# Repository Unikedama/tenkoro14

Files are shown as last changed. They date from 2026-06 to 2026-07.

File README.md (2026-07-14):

# Tenkoro14

**トラックボール搭載 右手用テンキーデバイス**

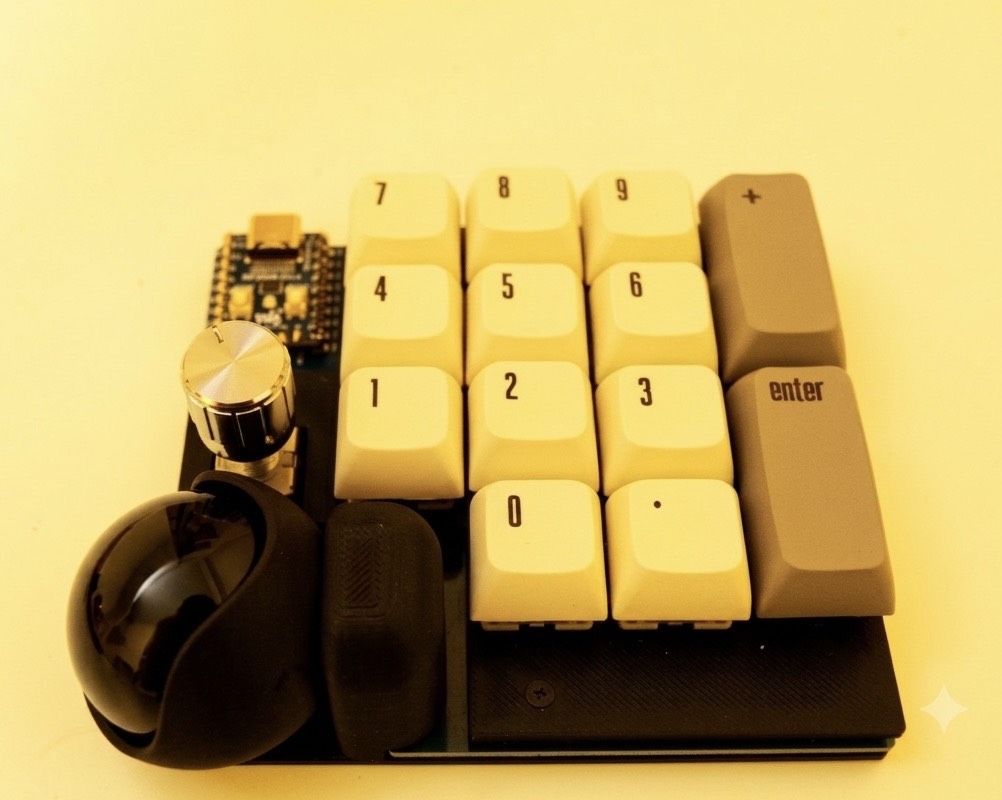
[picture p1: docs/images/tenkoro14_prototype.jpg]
Tenkoro14


---

## 概要

Tenkoro14は、トラックボールマウスとテンキーの機能を1台に凝縮した右手用デバイスです。

マウスとテンキーの間で手を移動させることなく、トラックボールでセルを選択してそのまま数値入力できます。Excelなどの表計算ソフトでの作業効率が大幅に向上します。

### 特徴

- **14キー**：Numpad 0〜9、`.`、`Enter`、`+`、カスタマイズ可能な1キー
- **トラックボール**：Keyball方式（PMW3610センサー）
- **オートマウスレイヤー**：トラックボール操作時に自動でマウスレイヤーに切り替え
- **ロータリーエンコーダ対応**：1キーをロータリーエンコーダに換装可能
- **Keyballトラックボールケース互換**：Keyball用ケースがそのまま使用可能
- **ダイオードレス設計**：はんだづけ箇所を最小限に
- **ホットスワップ＆直付け対応**：初心者から上級者まで対応

---

## 使用例

- **Excel / スプレッドシート**：トラックボールでセルを選択 → そのまま数値入力
- **DAW / 動画編集**：ロータリーエンコーダで音量・タイムライン操作
- **特定アプリ専用デバイス**：Vialでレイヤーをカスタマイズ

---

## スペック

| 項目 | 内容 |
|---|---|
| キー数 | 14キー |
| マイコン | RP2040 Zero |
| トラックボールセンサー | PMW3610 |
| トラックボールケース | Keyball互換 |
| キースイッチ | MX互換（ホットスワップ / 直付け両対応） |
| ファームウェア | QMK / Vial |
| 接続 | USB-C |

---

## 必要部品（BOM）

### 共通部品（すべての構成で必要）

| 部品 | 数量 | 備考 |
|---|---|---|
| PCB | 1 | |
| L字コンスルー 7pin（マックエイト） | 1 | PMW3610接続用・キット同梱 |
| PMW3610 ブレイクアウトボード | 1 | roBa互換品・キット同梱 |
| トラックボールケース | 1 | Keyball用互換品・キット同梱 |
| ピンヘッダ（9pin×2、5pin×1） | 1セット | RP2040 Zero取り付け用・キット同梱 |
| RP2040 Zero | 1 | |
| キースイッチ（MX互換） | 14 | |
| キーキャップ（1U） | 11〜12 | テンキー用を推奨（※下記注意事項参照） |
| キーキャップ（2U） | 2 | |
| ホットスワップソケット | 14 | 直付けの場合は不要 |
| M1.7ネジ | 2 | トラックボールケース固定用・キット同梱 |
| トラックボール（ボール） | 1 | 推奨：25mm／34mmも使用可能（※下記注意事項参照） |
| ロータリーエンコーダ EC11 | 0〜1 | オプション |
| M2スペーサー（7mm） | 4 | ミドルアクリル（3mm）込みの高さ |
| M2ネジ（4〜5mm） | 8 | |
| USBケーブル（Type-C） | 1 | |

### プレート（いずれかを選択）

| 構成 | トッププレート | ミドルアクリル | ボトムプレート | 入手方法 |
|---|---|---|---|---|
| **キット** | FR4（同梱） | 透明アクリル（同梱） | 透明アクリル（同梱） | キット購入 |
| **PCBのみ／自作** | STLデータで3Dプリント可 | STLデータで3Dプリント可 | STLデータで3Dプリント可 | 本リポジトリのデータを使用 |
| **PCBのみ／発注** | FR4データで発注（JLCPCB等） | アクリルデータで発注（Elecrow等） | アクリルデータで発注（Elecrow等） | 本リポジトリのデータを使用 |

> ミドルアクリルはロータリーエンコーダ搭載位置に切り欠きあり。

### キーキャップについて

テンキー用キーキャップセットの使用を推奨します。

> ⚠️ 一般的なテンキー用キーキャップセットでは、`0`キーが**2U**（横2倍サイズ）で付属している場合があります。Tenkoro14では`0`キーに**1U**のキーキャップが必要です。購入の際はセット内容をご確認ください。

### トラックボール（ボール）のサイズについて

用途に合わせてボールサイズを選んでください。

- **34mm**：操作性が高く、トラックボールマウスとしての使い勝手を重視する方に。`0`キーが若干打ちにくく感じる場合があります。
- **25mm**：テンキー入力をメインに使う方に。全キーを快適に操作できます。

---

## ファームウェア

### ダウンロード

ファームウェア `tenkoro14_vial.uf2` は [`firmware/`](firmware/) または
[**Releases**](../../releases/latest) から入手できます。

> 🛠 自作用の設計データ（プレート切削用DXF・各STL・3Dプリントケース）は
> [`hardware/`](hardware/) にまとめてあります。

### 書き込み方法

1. BOOTボタンを押しながらUSB接続（または BOOTボタンを押しながらリセット）
2. `RPI-RP2` ドライブとして認識される
3. `tenkoro14_vial.uf2` をドライブにコピー
4. 自動的に再起動してキーボードとして認識される

### Vialでキーマップを変更

[Vial](https://get.vial.today/) を使用してキーマップをカスタマイズできます。

---

## ビルドガイド

→ [buildguide.md](docs/buildguide.md) を参照してください。

---

## 部品の購入先

以下のショップで必要な部品を購入できます。

| 部品 | 購入先 |
|---|---|
| RP2040 Zero | [Talpkeyboard](https://talpkeyboard.net/) / [遊舎工房](https://shop.yushakobo.jp/) |
| キースイッチ（MX互換） | [Talpkeyboard](https://talpkeyboard.net/) / [遊舎工房](https://shop.yushakobo.jp/) |
| ホットスワップソケット | [Talpkeyboard](https://talpkeyboard.net/) / [遊舎工房](https://shop.yushakobo.jp/) |
| トラックボール（ボール） | [遊舎工房](https://shop.yushakobo.jp/) / Amazon |
| キーキャップ | [Talpkeyboard](https://talpkeyboard.net/) / [遊舎工房](https://shop.yushakobo.jp/) |

---

## キーアサインのおすすめ

テンキー入力時に数字の打ち間違いが多い場面では、`+`キーに **`BS`または`Del`** を割り当てることをおすすめします。Vialで自由にカスタマイズできます。

## レイヤー構成（デフォルト）

| レイヤー | 内容 |
|---|---|
| Layer 0 | テンキー（Numpad） |
| Layer 1 | オートマウス（トラックボール操作時に自動切替） |
| Layer 2 | カスタム |

---

## ライセンス

- ファームウェア：[GPL-2.0](LICENSE)
- ハードウェア設計：© Unikedama

---

## クレジット・スペシャルサンクス
- トラックボール付きキーボード keyballの製作者：ヨーキース様をはじめとする、自作キーボード界隈の先輩方
- トラックボールケース：[kepeo](https://www.thingiverse.com/kepeo) 氏の設計（[CC BY 4.0](https://creativecommons.org/licenses/by/4.0/)）を一部改変して使用
- ファームウェア：[QMK Firmware](https://qmk.fm/) / [Vial](https://get.vial.today/)

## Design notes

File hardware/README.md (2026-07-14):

# hardware

tenkoro14 の自作用データ一式。

## plates_dxf/ — プレート切削発注用DXF（M2スペーサ穴あり）
| ファイル | 用途 | 材質 |
|---|---|---|
| tenkoro14_v1_TopPlate_FR4_99.9x89.96.dxf | トッププレート | FR4 1.6mm |
| tenkoro14_v1_MiddlePlate_acryl3mm_99.9x89.96.dxf | ミドルプレート | アクリル 3mm |
| tenkoro14_v1_BottomPlate_acryl2mm_99.97x89.88.dxf | ボトムプレート | アクリル 2mm |
| tenkoro14_v1_BottomPlate_Caseyou.dxf | ボトム（Caseyou発注用の別版） | アクリル 2mm |

## plates_stl/ — 各プレートのSTL（形状確認用）

## trackball_case/ — トラックボール部の3Dプリントケース（top/bottom）
kepeo氏データ（CC BY 4.0）の改変。

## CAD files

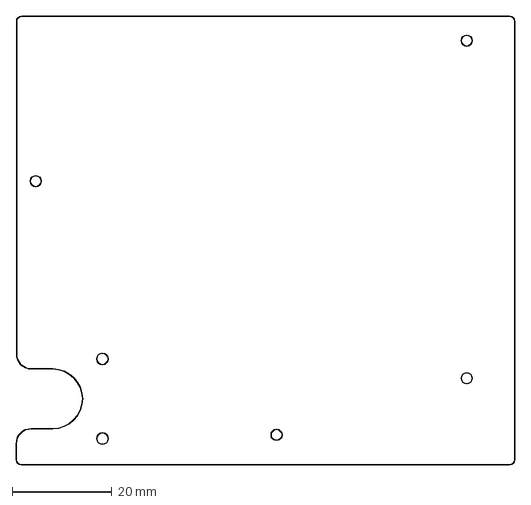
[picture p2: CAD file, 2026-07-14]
hardware/plates_dxf/tenkoro14_v1_BottomPlate_acryl2mm_99.97x89.88.dxf
100.0 x 89.9 mm

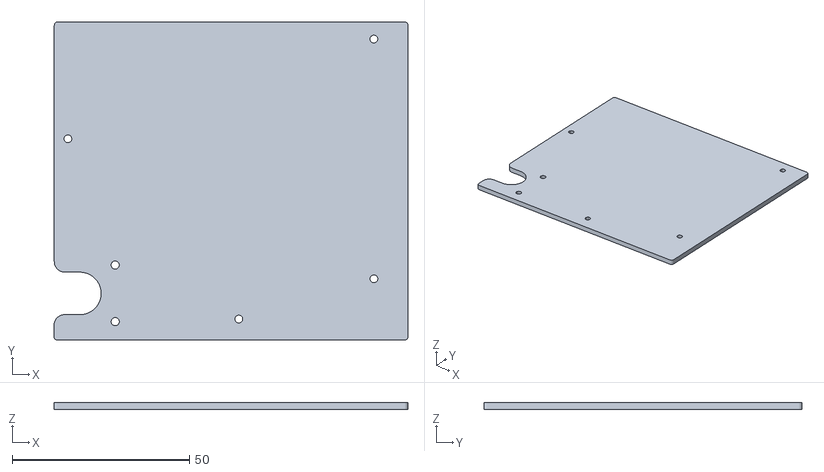
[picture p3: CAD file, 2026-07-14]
hardware/plates_stl/tenkoro_V1_bottom.stl
100.0 x 89.9 x 2.00

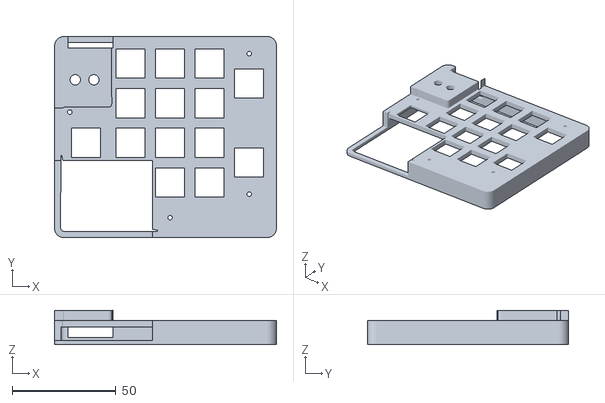
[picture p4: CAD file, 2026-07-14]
hardware/trackball_case/tenkoro14_trackball_case_top.stl
107.0 x 96.9 x 16.6

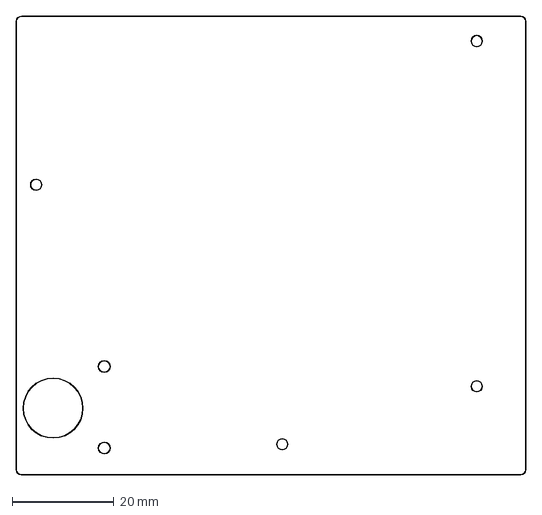
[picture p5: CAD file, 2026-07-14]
hardware/plates_dxf/tenkoro14_v1_BottomPlate_Caseyou.dxf
100.0 x 89.9 mm

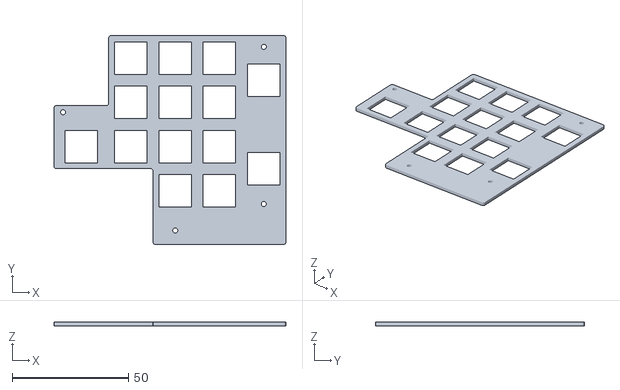
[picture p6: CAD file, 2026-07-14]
hardware/plates_stl/tenkoro14_v1_top.stl
99.9 x 90.0 x 1.60

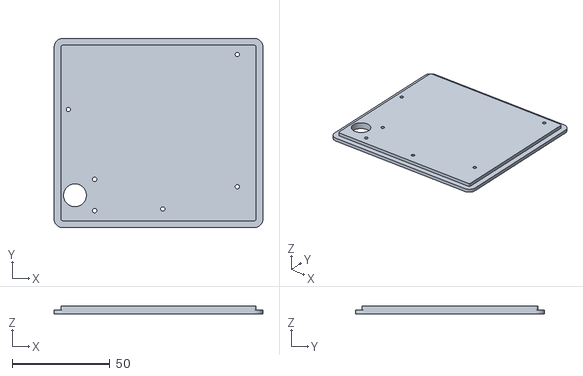
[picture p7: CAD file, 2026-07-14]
hardware/trackball_case/tenkoro14_trackball_case_bottom.stl
107.0 x 96.9 x 4.00

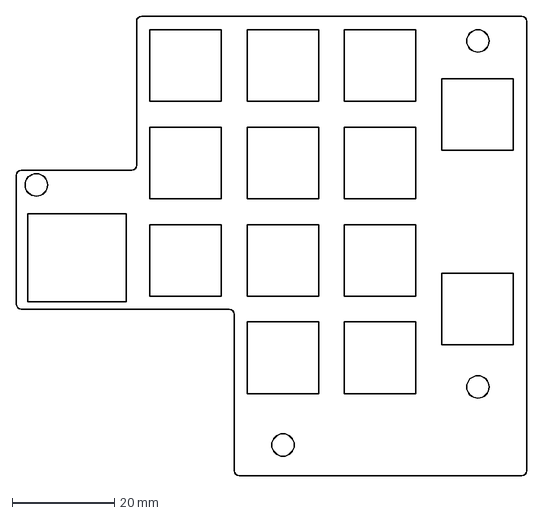
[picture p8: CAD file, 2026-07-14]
hardware/plates_dxf/tenkoro14_v1_MiddlePlate_acryl3mm_99.9x89.96.dxf
99.9 x 90.0 mm

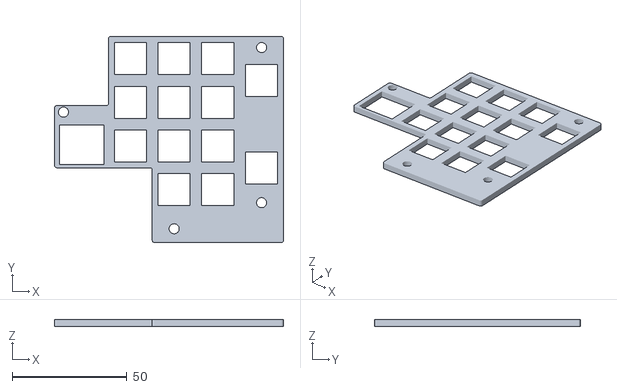
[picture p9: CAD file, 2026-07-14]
hardware/plates_stl/tenkoro14_v1_middle.stl
99.9 x 90.0 x 3.00

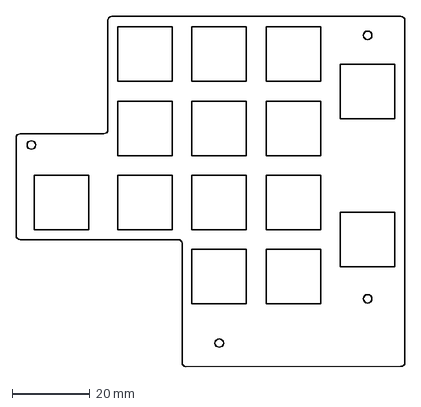
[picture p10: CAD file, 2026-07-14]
hardware/plates_dxf/tenkoro14_v1_TopPlate_FR4_99.9x89.96.dxf
99.9 x 90.0 mm

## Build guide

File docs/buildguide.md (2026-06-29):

# Tenkoro14 ビルドガイド

## 目次

1. [内容物確認](#1-内容物確認)
2. [必要な工具](#2-必要な工具)
3. [ホットスワップソケットのはんだ付け（オプション）](#3-ホットスワップソケットのはんだ付けオプション)
4. [RP2040 Zeroの取り付け](#4-rp2040-zeroの取り付け)
5. [PMW3610ブレイクアウトボードの取り付け](#5-pmw3610ブレイクアウトボードの取り付け)
6. [キースイッチの取り付け](#6-キースイッチの取り付け)
7. [ファームウェアの書き込み](#7-ファームウェアの書き込み)
8. [動作確認](#8-動作確認)
9. [プレートの組み立て](#9-プレートの組み立て)
10. [トラックボールケースの取り付け](#10-トラックボールケースの取り付け)
11. [完成・キーマップのカスタマイズ](#11-完成キーマップのカスタマイズ)

---

## 1. 内容物確認

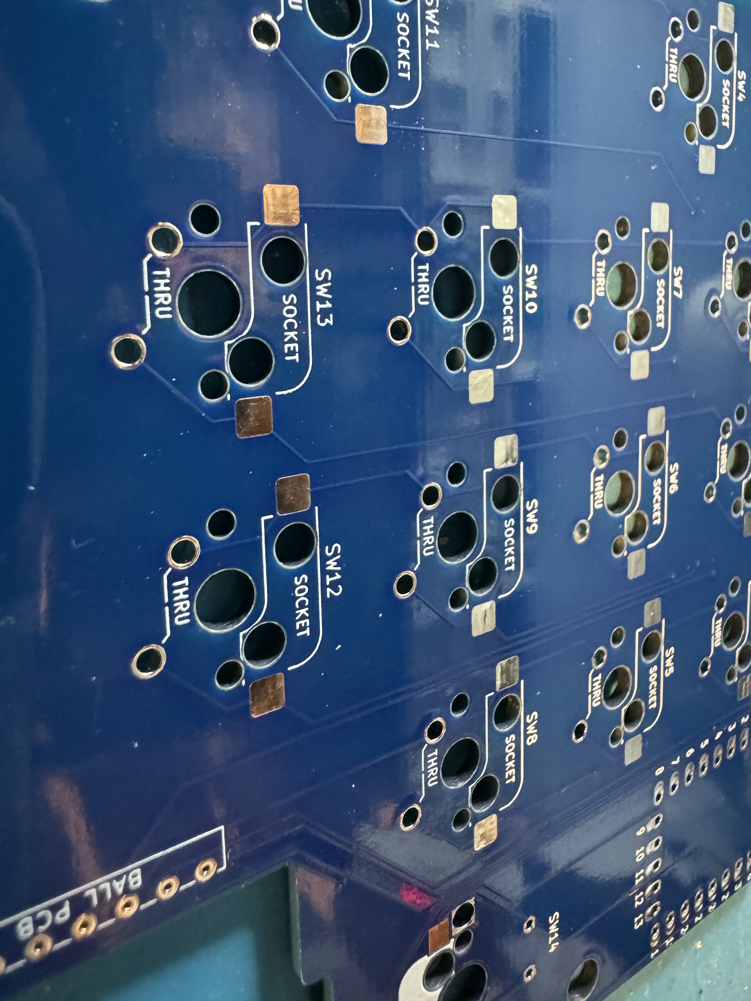
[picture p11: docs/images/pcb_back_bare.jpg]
PCB裏面


キット版には以下が含まれています。

| 部品 | 数量 |
|---|---|
| PCB | 1 |
| L字コンスルー 7pin（マックエイト） | 1 | PMW3610接続用 |
| PMW3610 ブレイクアウトボード | 1 |
| トラックボールケース | 1 |
| ピンヘッダ（9pin×2、5pin×1） | 1セット | RP2040 Zero取り付け用 |
| トッププレート（FR4） | 1 |
| ミドルアクリル（3mm） | 1 |
| ボトムアクリル（透明） | 1 |
| M2スペーサー（7mm） | 4 |
| M2ネジ（4〜5mm） | 8 |
| M1.7ネジ | 2 |

以下は別途ご用意ください。

| 部品 | 数量 | 備考 |
|---|---|---|
| RP2040 Zero | 1 | |
| キースイッチ（MX互換） | 14 | |
| ホットスワップソケット | 14 | 直付けの場合は不要 |
| キーキャップ（1U） | 11〜12 | テンキー用推奨。`0`キーは1U必要（※注意参照） |
| キーキャップ（2U） | 2 | |
| トラックボール（ボール） | 1 | 25mm推奨、34mm使用可 |
| ロータリーエンコーダ EC11 | 0〜1 | オプション |
| USBケーブル（Type-C） | 1 | |

---

## 2. 必要な工具

| 工具 | 備考 |
|---|---|
| はんだごて | 温度調整できるものを推奨 |
| はんだ | 0.8mm程度 |
| フラックス | あると便利 |
| ニッパー / ペンチ | ピンヘッダのカットに使用 |
| ピンセット | ソケット取り付けに便利 |
| テスター | 動作確認に便利（必須ではない） |

---

## 3. ホットスワップソケットのはんだ付け（オプション）

キースイッチをホットスワップ対応にする場合に行います。直接はんだ付けする場合はスキップしてください。

1. PCB裏面のソケット取り付けパッドにフラックスを塗る
2. ソケットをパッドに合わせて置く
3. ソケットの片側のパッドにはんだを盛り、固定する
4. もう片側もはんだ付けする
5. 14個すべて取り付ける

> ⚠️ ソケットの向きに注意してください。左右が逆になるとスイッチが入りません。

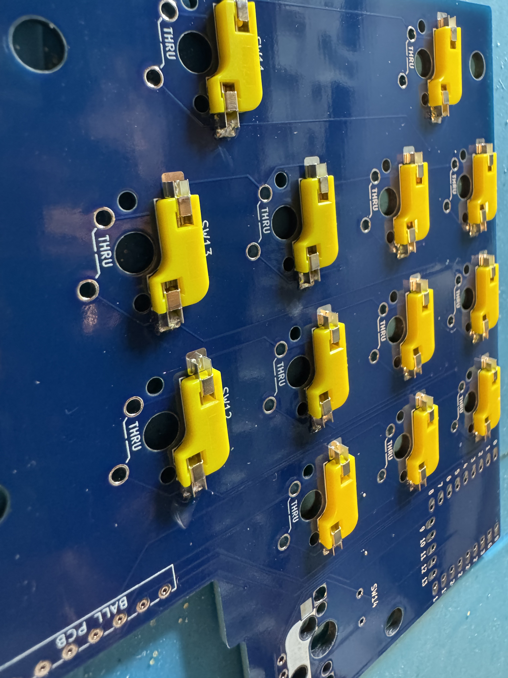
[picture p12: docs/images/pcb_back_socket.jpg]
ホットスワップソケット取り付け後


---

## 4. RP2040 Zeroの取り付け

ピンヘッダを使用してRP2040 Zeroを取り付けます。

1. キット付属のピンヘッダ（9pin×2本、5pin×1本、あらかじめカット済み）をPCBのRP2040 Zero用ランドに差し込む（長い方を上にする）
2. RP2040 Zeroをピンヘッダに差し込む
3. RP2040 Zeroが水平になっていることを確認する
4. PCB側をはんだ付けする
5. RP2040 Zero側をはんだ付けする

> 💡 ピンが長すぎる場合は、RP2040 Zeroを差し込んだ状態でペンチなどでカットしてから、はんだ付けを行うと整えやすいです。

---

## 5. PMW3610ブレイクアウトボードの取り付け

L字コンスルー（7pin）を使用して取り付けます。Keyball / roBaと同じ方式で抜き差し可能です。

1. L字コンスルーのU字型になっていない方をPCB表面のPMW3610用ランドに差し込む
2. マスキングテープで浮かないよう固定する
3. PCB裏面からはんだ付けする
4. PMW3610ブレイクアウトボードをL字コンスルーに垂直に差し込む

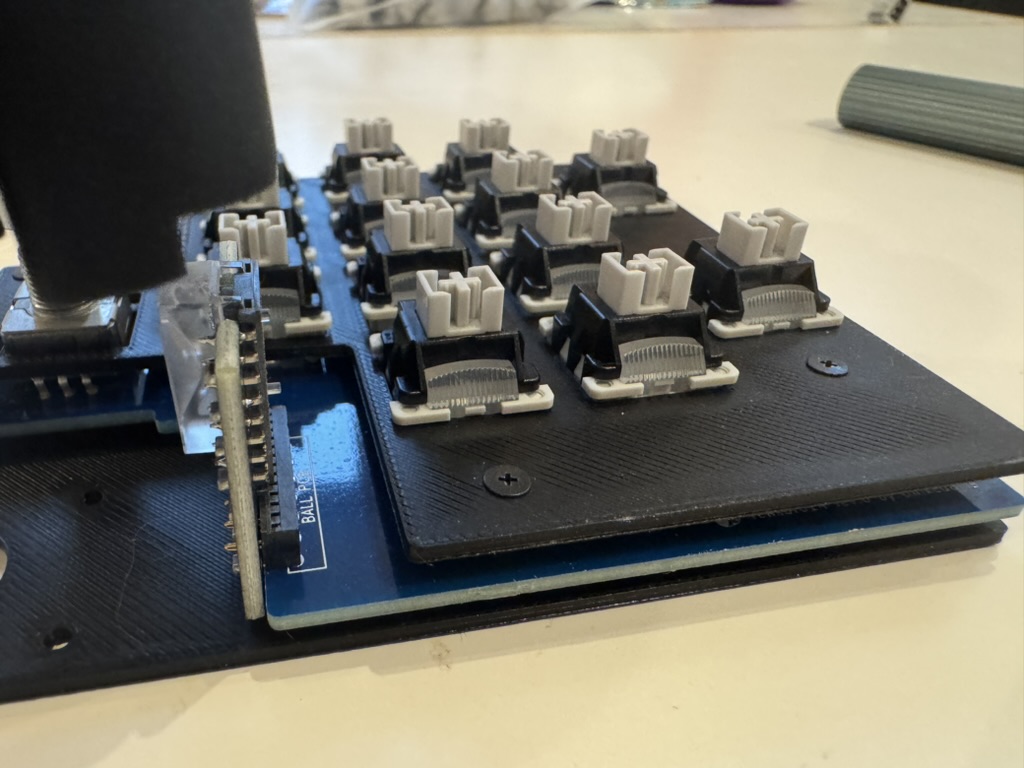
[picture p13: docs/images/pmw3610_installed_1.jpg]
PMW3610とL字コンスルーの接続①


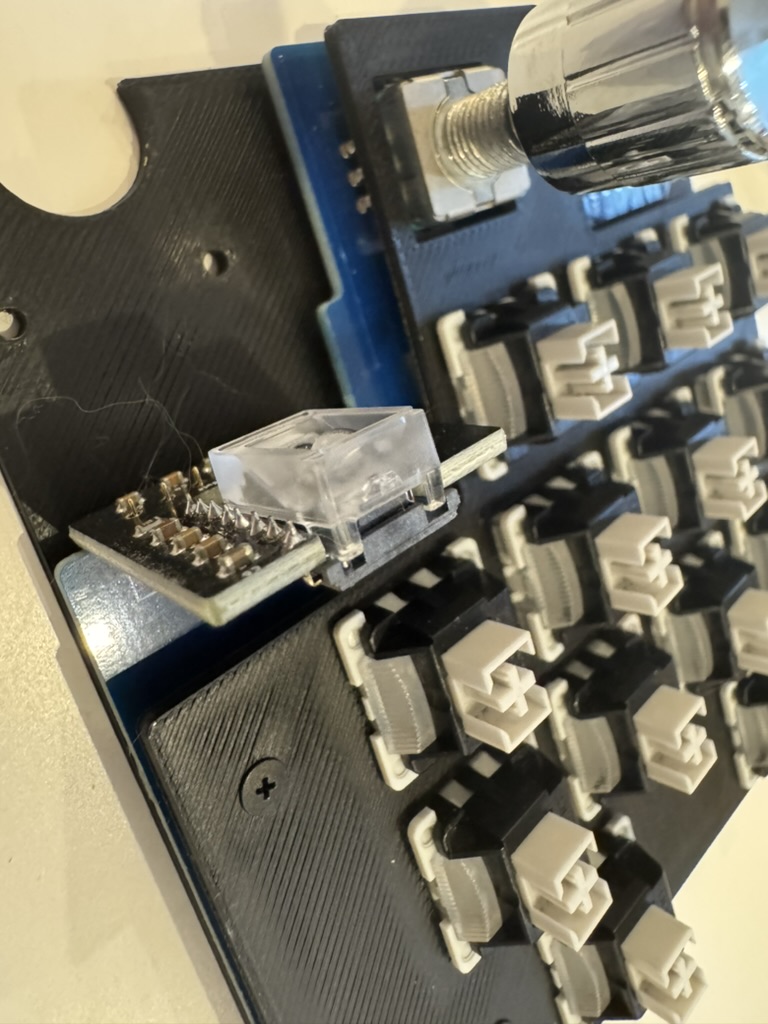
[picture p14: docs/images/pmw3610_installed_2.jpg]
PMW3610とL字コンスルーの接続②


> ⚠️ カプトンテープ（保護フィルム）がセンサー面に貼ってある場合は、取り付け前に剥がしてください。剥がし忘れるとトラックボールが動作しません。

---

## 6. キースイッチの取り付け

### ホットスワップソケットを使用する場合

1. トッププレートにキースイッチをはめ込む
2. スイッチの足がソケットの穴に合っていることを確認して押し込む

### 直接はんだ付けする場合

1. トッププレートにキースイッチをはめ込む
2. PCB裏面からスイッチの足をはんだ付けする

> ロータリーエンコーダを使用する場合は、該当箇所にEC11を取り付けてはんだ付けしてください。

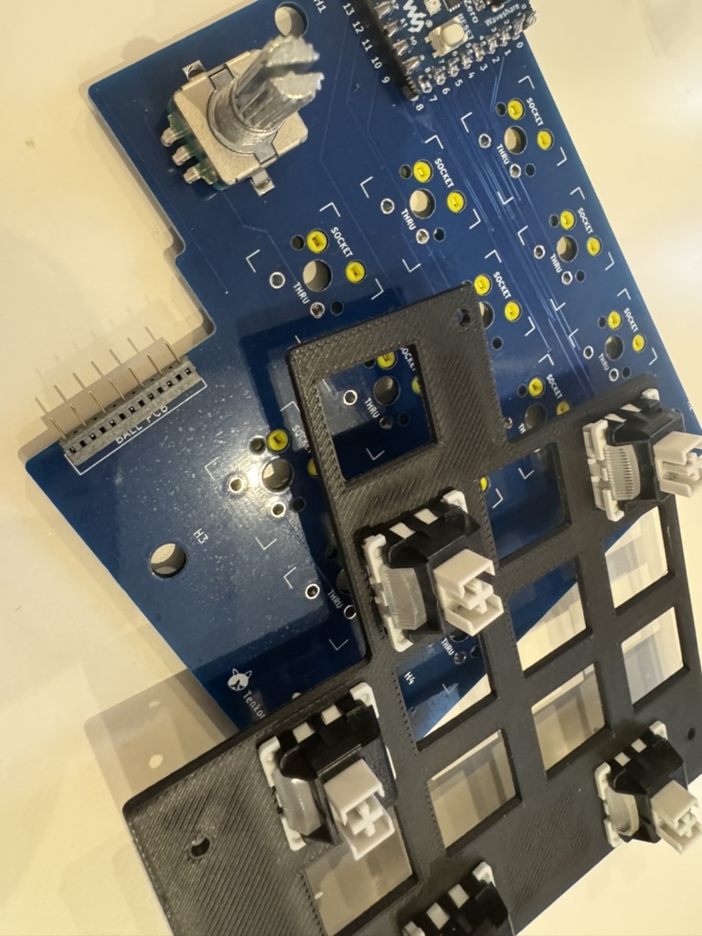
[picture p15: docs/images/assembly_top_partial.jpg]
スイッチ取り付け中


---

## 7. ファームウェアの書き込み

1. RP2040 ZeroのBOOTボタンを押しながらUSBケーブルを接続する
2. `RPI-RP2` というドライブとして認識される
3. [Releases](../../releases) からダウンロードした `tenkoro14_vial.uf2` をドライブにコピーする
4. 自動的に再起動してキーボードとして認識される

---

## 8. 動作確認

プレートを組み立てる前に動作確認を行います。

1. USBケーブルで接続する
2. [Vial](https://get.vial.today/) を起動してキーボードが認識されているか確認する
3. ピンセットなどでスイッチのランド（またはソケット）を短絡させてキー入力を確認する
4. トラックボールを動かしてカーソルが動くか確認する

> macOSの場合、Vialの認識には「システム設定」→「プライバシーとセキュリティ」→「入力監視」でVialを許可する必要があります。

---

## 9. プレートの組み立て

1. ボトムアクリルの保護シートを剥がす
2. ボトムアクリルの4隅にM2スペーサーをM2ネジで固定する
3. ミドルアクリルの保護シートを剥がし、スペーサーの上に置く
4. PCBをミドルアクリルの上に置く
5. トッププレートをPCBの上に置く
6. 上からM2ネジで固定する

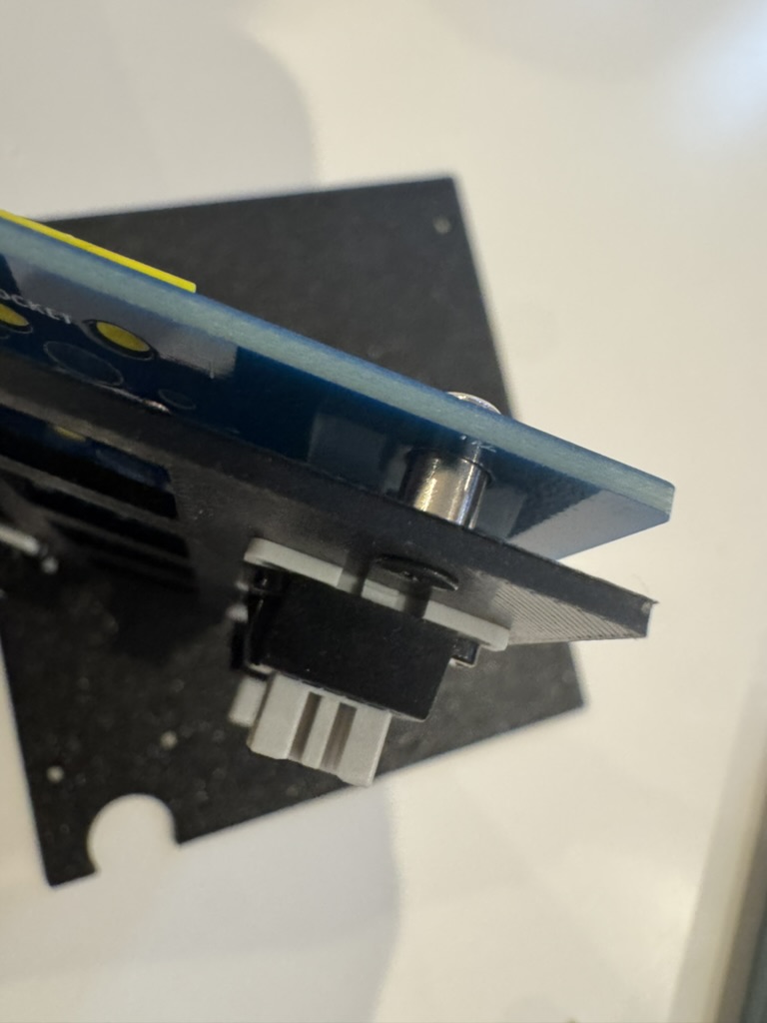
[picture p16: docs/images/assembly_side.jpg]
プレート側面（スタック構造）


---

## 10. トラックボールケースの取り付け

1. PMW3610のレンズをブレイクアウトボードに取り付ける（未取り付けの場合）
2. トラックボールケースをPCB上の所定位置に合わせる
3. M1.7ネジ2本で固定する
4. トラックボール（ボール）をケースにはめ込む

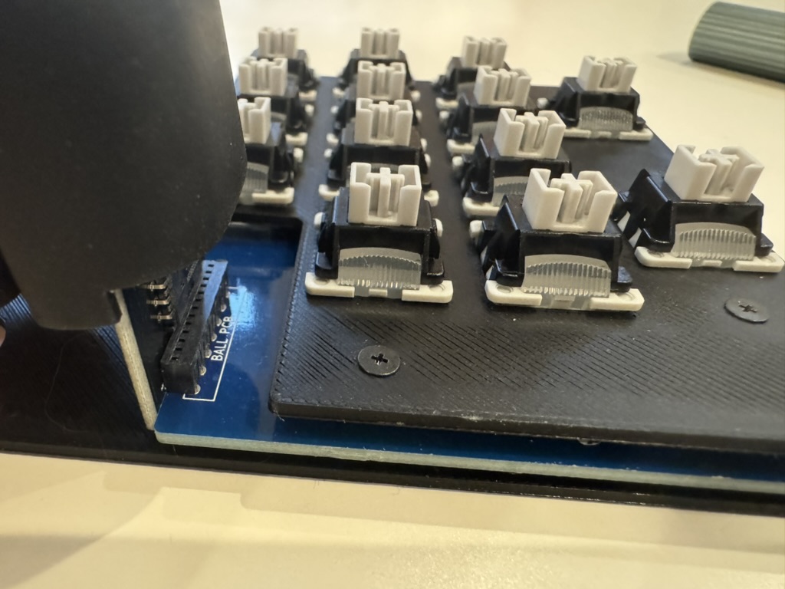
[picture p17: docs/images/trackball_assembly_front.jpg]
トラックボールケース取り付け（正面）


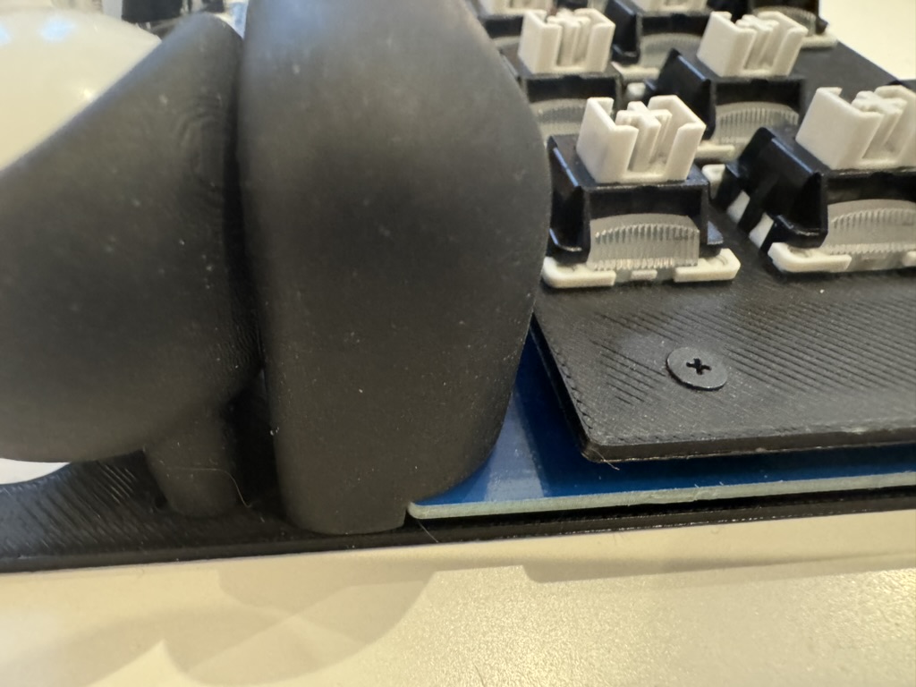
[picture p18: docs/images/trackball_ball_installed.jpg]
トラックボール装着後（側面）


---

## 11. 完成・キーマップのカスタマイズ

お疲れ様でした！完成です。

完成品

Vialを使ってキーマップを自由にカスタマイズできます。

### おすすめ設定

- `+`キーに `BS` または `Del` を割り当てると、テンキー入力時の打ち間違いを素早く修正できます。
- トラックボール操作時はオートマウスレイヤーが自動的に有効になります。

### トラブルシューティング

| 症状 | 対処法 |
|---|---|
| キーボードが認識されない | BOOTボタンを押しながら再接続してuf2を再書き込み |
| Vialに表示されない | macOSの入力監視の権限を確認 |
| トラックボールが動かない | カプトンテープが剥がれているか確認。レンズが取り付けられているか確認 |
| 特定のキーが反応しない | ホットスワップソケットのはんだを確認。スイッチの足が曲がっていないか確認 |

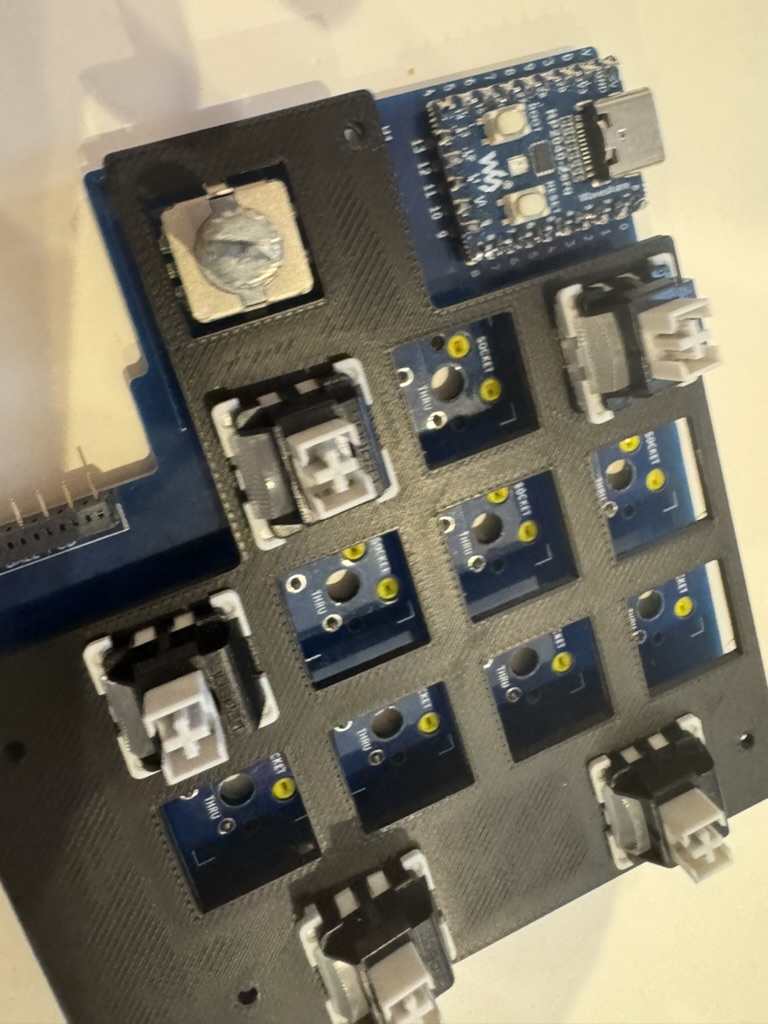
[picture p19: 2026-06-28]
docs/images/assembly_top_complete.jpg

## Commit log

2026-06-28 Replace prototype image: png -> jpg
2026-06-29 Update BOM: pin headers pre-cut (9pin×2, 5pin×1)
2026-07-14 Add v1.0 firmware and hardware data (plates DXF/STL, trackball case)
    [tenkoro14_trackball_case_bottom.stl, tenkoro14_trackball_case_top.stl, tenkoro14_v1_BottomPlate_Caseyou.dxf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]
